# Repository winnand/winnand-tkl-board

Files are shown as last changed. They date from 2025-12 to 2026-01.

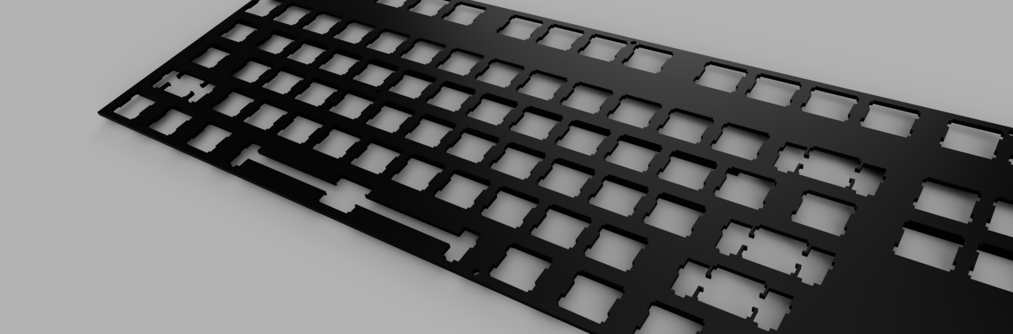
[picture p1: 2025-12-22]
Images/KB Plate.png

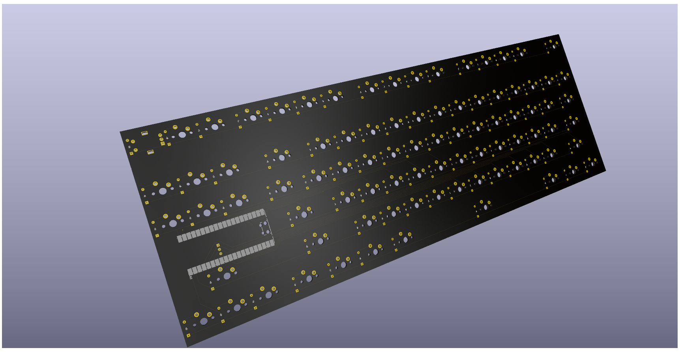
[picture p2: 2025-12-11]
Images/KeyboardPCBBackBare.png

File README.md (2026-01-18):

# The Winnand TKL Keyboard

This project is a custom keyboard based off of JoeScotto's guides from YouTube. It is a standard TKL Board which replaces the Pause key with a rotary encoder. It uses QMK with Vial support for on-the-go layout customization.

I made this project because I enjoyed the idea of having a keyboard that I made myself, with the features and rigidity of a top-of-the-line keyboard. I hoped that it would teach me more about firmware and microcontrollers for future projects, and have a good keyboard that I would be able to use for many years to come. 
Full CAD
KeyboardPCBFrontBare
Isogrid
KB Case Full
KB Case Render 1
KB Plate Underside
KB Plate
KeyboardPCBBackBare
KeyboardPCBFrontBare

# BOM

|Part # |Min. Quantity |Name on Seller Website |Description |Link |Color/Size |Quantity|Unit Price ($)|Total Price ($)|Running Total ($)|
|---|---|---|---|---|---|---|---|---|---|
|MX-keyboard switches |86 |Outemu Switch Mechanical Keyboard Switch 3Pin Clicky Linear Tactile Silent Switches RGB LED SMD Gaming Compatible With MX Switch|Keyboard Switches|https://www.aliexpress.us/item/3256802192387196.html  |Color: Dust-Proof Purple Axis Body: 90PCS |1 |$10.31 |$10.31 |$10.31 |
|Red LED |87 |100pcs 5mm LED Diode F5 Assorted Kit White Green Red Blue Yellow Orange Pink Purple Warm White DIY Light Emitting Diode |Diodes |https://www.aliexpress.us/item/3256806276743323.html  |Color: Red-Red |1 |$2.19 |$2.19 |$12.50 |
|EC11 Rotary Encoder |1 |5PCS/LOT 20 Position 360 Degree Rotary Encoder EC11 w Push Button 5Pin Handle Long 15/20MM With A Built In Push Button Switch |Rotary Encoder |https://www.aliexpress.us/item/3256805796819763.html? |15MM Half handle |1 |$3.30 |$3.30 |$15.80 |
|Raspberry Pi Pico |1 |Raspberry Pi Pico |Microcontroller  |https://www.sparkfun.com/raspberry-pi-pico.html | |0 |$4.60 |$0.00 |$15.80 |
|Micro USB male to panel mount USB C female|1 |USB 3.1 Type C Micro Usb2.0 With Panel Mount Screw Extension Cable Cord USB C Male To Female Extending Wire Extender Data Cord  |Adapter Cable |https://www.aliexpress.us/item/3256806244885684.html  |A3 |1 |$2.69 |$2.69 |$18.49 |
|M2 x 6mm Button Head screw |11 |10/50pcs M1.6 M2 M2.5 M3 M4 M5 M6 M8 Black Grade 10.9 Steel ISO7380 Hexagon Hex Socket Head Button Mushroom Allen Bolt Screw |Mounting Screws  |https://www.aliexpress.us/item/2251832782727837.html  |Size: M2 (50pcs) Length: 6mm |1 |$1.07 |$1.07 |$19.56 |
|MX Keycaps |TKL Layout |104pcs ABS Universal Mechanical Keyboard Keycaps Ergonomic Blank Keycaps For Cherry MX Keyboard Replacement OEM Backlit Key Cap |Keycaps |https://www.aliexpress.us/item/3256808802544300.html  |Red black |1 |$11.48 |$11.48 |$31.04 |
|Plate Mount Stabilizers |1x 6.25U 4x 2U|KEYCOOL V3 PCB Plate Mounted Stabilizer for Gaming Mechanical Keyboard Lubrication Satellite Switches for 1.2mm 1.6mm PCB 6.25U |Stabilizers |https://www.aliexpress.us/item/3256808467378574.html  |Black 4 in 1 |1 |$3.01 |$3.01 |$34.05 |
|M2, OD4mm Heatset Inserts |11 |M2 M2.5 M3 M4 M5 M6 Brass Hot Melt Insert Knurled Nut Thread Heat Molding Double Twill Injection Embedment Nut For 3D Printer |Heatset Inserts  |https://www.aliexpress.us/item/3256803396040989.html  |Size: M2(OD4mm)  Color: Length 5mm 50pcs |1 |$2.27 |$2.27 |$36.32 |
|Winnand-TKL PCB |1 |JLCPCB |PCB |https://cart.jlcpcb.com/quote?spm=Jlcpcb.Homepage.1006|Defaults except: PCB Color: Black Via Covering: Untented |5 |$4.16 |$20.80 |$57.12 |
|ARGB lights |1 |Addressable ARGB 5V LED Strip 3Pin Computer PC Case Tape Light WS2812B SMD 5050 Flexible Changeable Color Gamer Desktop Lamp |Lights |https://www.aliexpress.us/item/3256802938234249.html? |Emitting Color: 1 x 0.5m 30leds  Color: IP30 Non waterproof|1 |$4.00 |$4.00 |$61.12 |

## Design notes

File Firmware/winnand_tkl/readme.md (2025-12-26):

# winnand_tkl

winnand_tkl

*A short description of the keyboard/project*

* Keyboard Maintainer: [Aditya Itnal](https://github.com/winnand)
* Hardware Supported: *The PCBs, controllers supported*
* Hardware Availability: *Links to where you can find this hardware*

Make example for this keyboard (after setting up your build environment):

    make winnand_tkl:default

Flashing example for this keyboard:

    make winnand_tkl:default:flash

See the [build environment setup](https://docs.qmk.fm/#/getting_started_build_tools) and the [make instructions](https://docs.qmk.fm/#/getting_started_make_guide) for more information. Brand new to QMK? Start with our [Complete Newbs Guide](https://docs.qmk.fm/#/newbs).

## Bootloader

Enter the bootloader in 3 ways:

* **Bootmagic reset**: Hold down the key at (0,0) in the matrix (usually the top left key or Escape) and plug in the keyboard
* **Physical reset button**: Briefly press the button on the back of the PCB - some may have pads you must short instead
* **Keycode in layout**: Press the key mapped to `QK_BOOT` if it is available

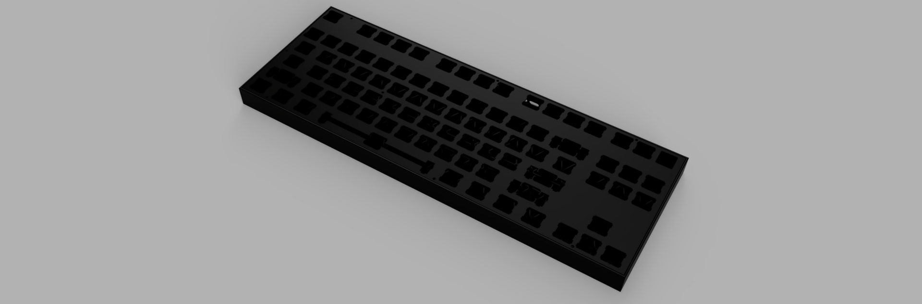
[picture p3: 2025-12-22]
Images/KB Case Full.png

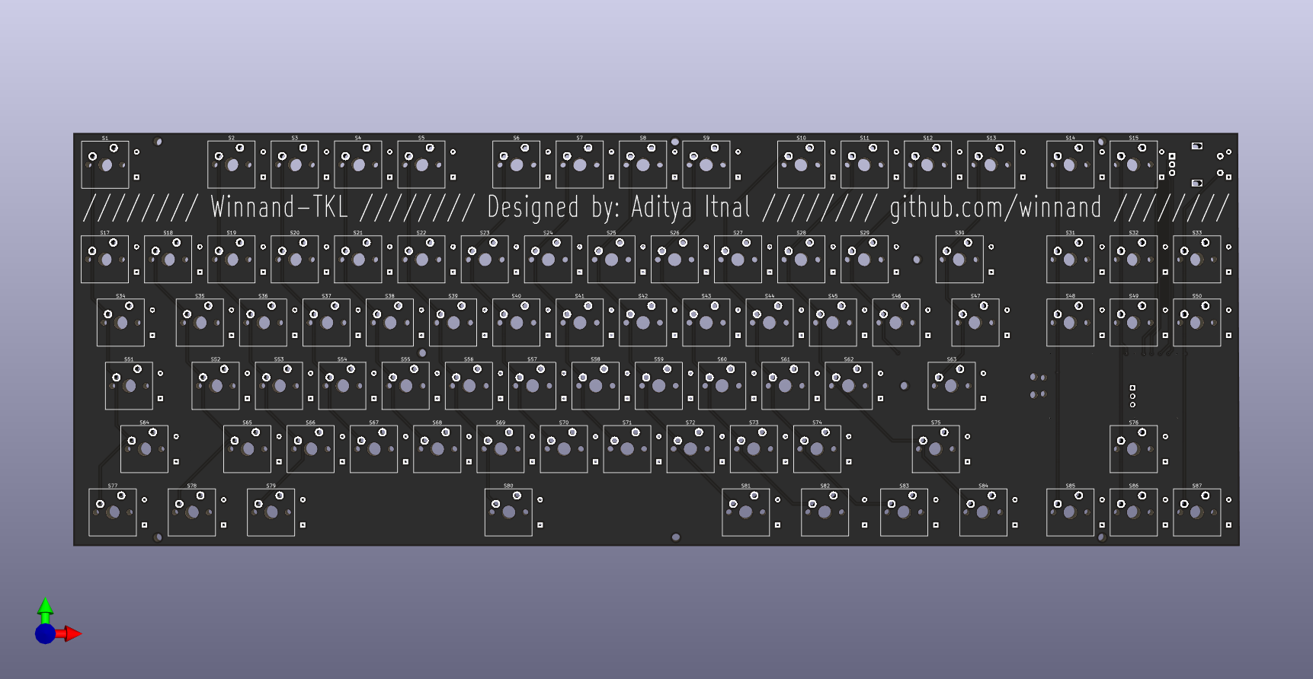
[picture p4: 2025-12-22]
Images/KeyboardPCBFrontBare.png

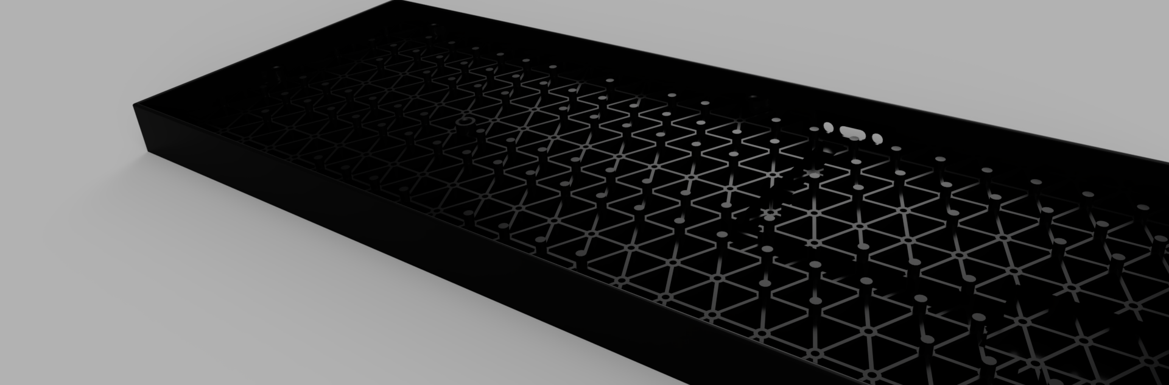
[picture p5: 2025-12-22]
Images/KB Case Render 1.PNG

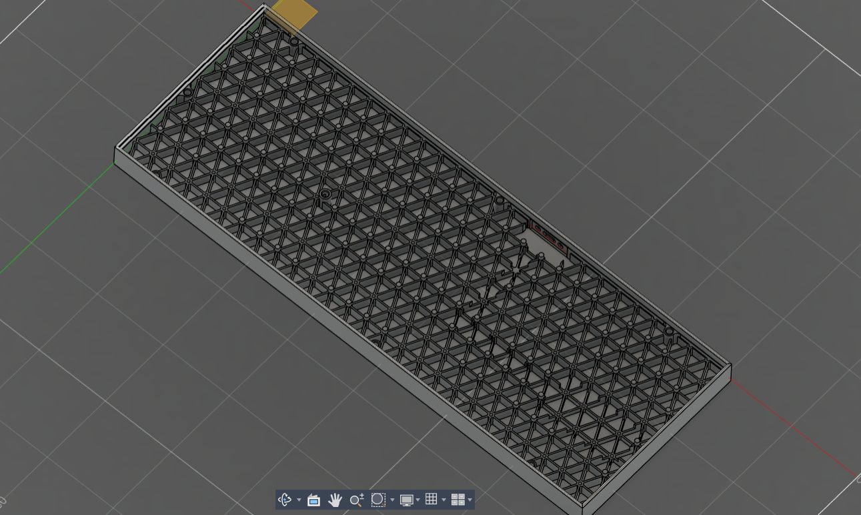
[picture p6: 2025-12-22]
Images/Isogrid.png

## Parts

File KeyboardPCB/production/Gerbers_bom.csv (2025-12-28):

Designator | Footprint | Quantity | Value | LCSC Part #
A0 | RaspberryPi_Pico_W_SMD_HandSolder | 1 | RaspberryPi_Pico_W
D1, D10, D11, D12, D13, D14, D15, D16, D17, D18, D19, D2, D20, D21, D22, D23, D24, D25, D26, D27, D28, D29, D3, D30, D31, D32, D33, D34, D35, D36, D37, D38, D39, D4, D40, D41, D42, D43, D44, D45, D46, D47, D48, D49, D5, D50, D51, D52, D53, D54, D55, D56, D57, D58, D59, D6, D60, D61, D62, D63, D64, D65, D66, D67, D68, D69, D7, D70, D71, D72, D73, D74, D75, D76, D77, D78, D79, D8, D80, D81, D82, D83, D84, D85, D86, D87, D9 | Diode_DO-35 | 87 | ~
J1 | PinHeader_1x04_P2.54mm_Vertical | 1 | Conn_01x04_Pin
S1, S10, S11, S12, S13, S14, S15, S17, S18, S19, S2, S20, S21, S22, S23, S24, S25, S26, S27, S28, S29, S3, S31, S32, S33, S35, S36, S37, S38, S39, S4, S40, S41, S42, S43, S44, S45, S46, S48, S49, S5, S50, S52, S53, S54, S55, S56, S57, S58, S59, S6, S60, S61, S62, S65, S66, S67, S68, S69, S7, S70, S71, S72, S73, S74, S76, S8, S85, S86, S87, S9 | MX_PCB_1.00u | 71 | ~
S30 | MX_PCB_2.00u | 1 | ~
S34, S47 | MX_PCB_1.50u | 2 | ~
S51 | MX_PCB_1.75u | 1 | ~
S63, S64 | MX_PCB_2.25u | 2 | ~
S75 | MX_PCB_2.75u | 1 | ~
S77, S78, S79, S81, S82, S83, S84 | MX_PCB_1.25u | 7 | ~
S80 | MX_PCB_6.25u | 1 | ~
SW0 | Encoder_EC11_MX | 1 | RotaryEncoder_Switch

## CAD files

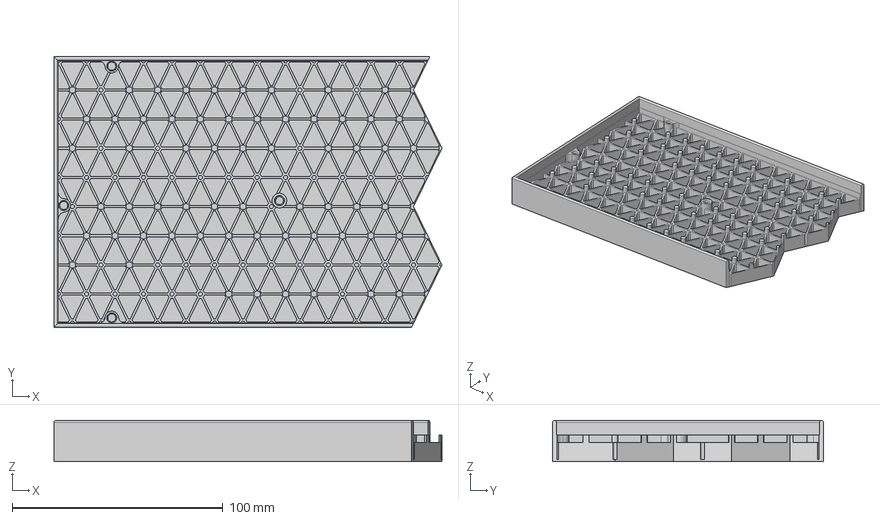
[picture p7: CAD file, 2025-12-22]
CAD/STEP Files for 3D Printing/Left Side.step
184.0 x 128.5 x 19.5 mm

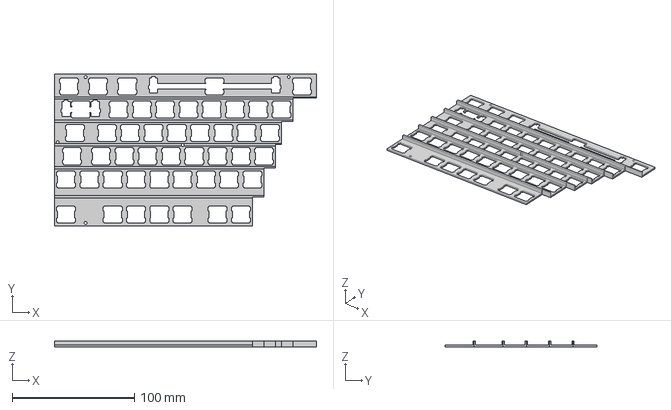
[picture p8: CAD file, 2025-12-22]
CAD/STEP Files for 3D Printing/Left Top plate.step
214.3 x 124.5 x 5.10 mm

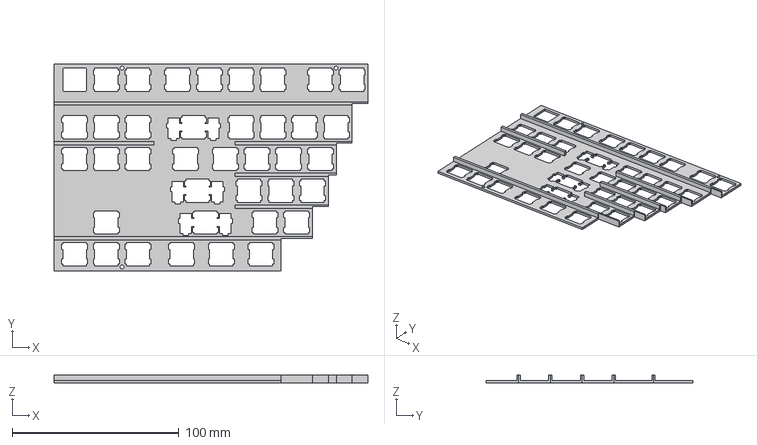
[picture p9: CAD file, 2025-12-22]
CAD/STEP Files for 3D Printing/Right Top Plate.step
188.6 x 124.5 x 5.10 mm

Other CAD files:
CAD/STEP Files for 3D Printing/Right Side.step

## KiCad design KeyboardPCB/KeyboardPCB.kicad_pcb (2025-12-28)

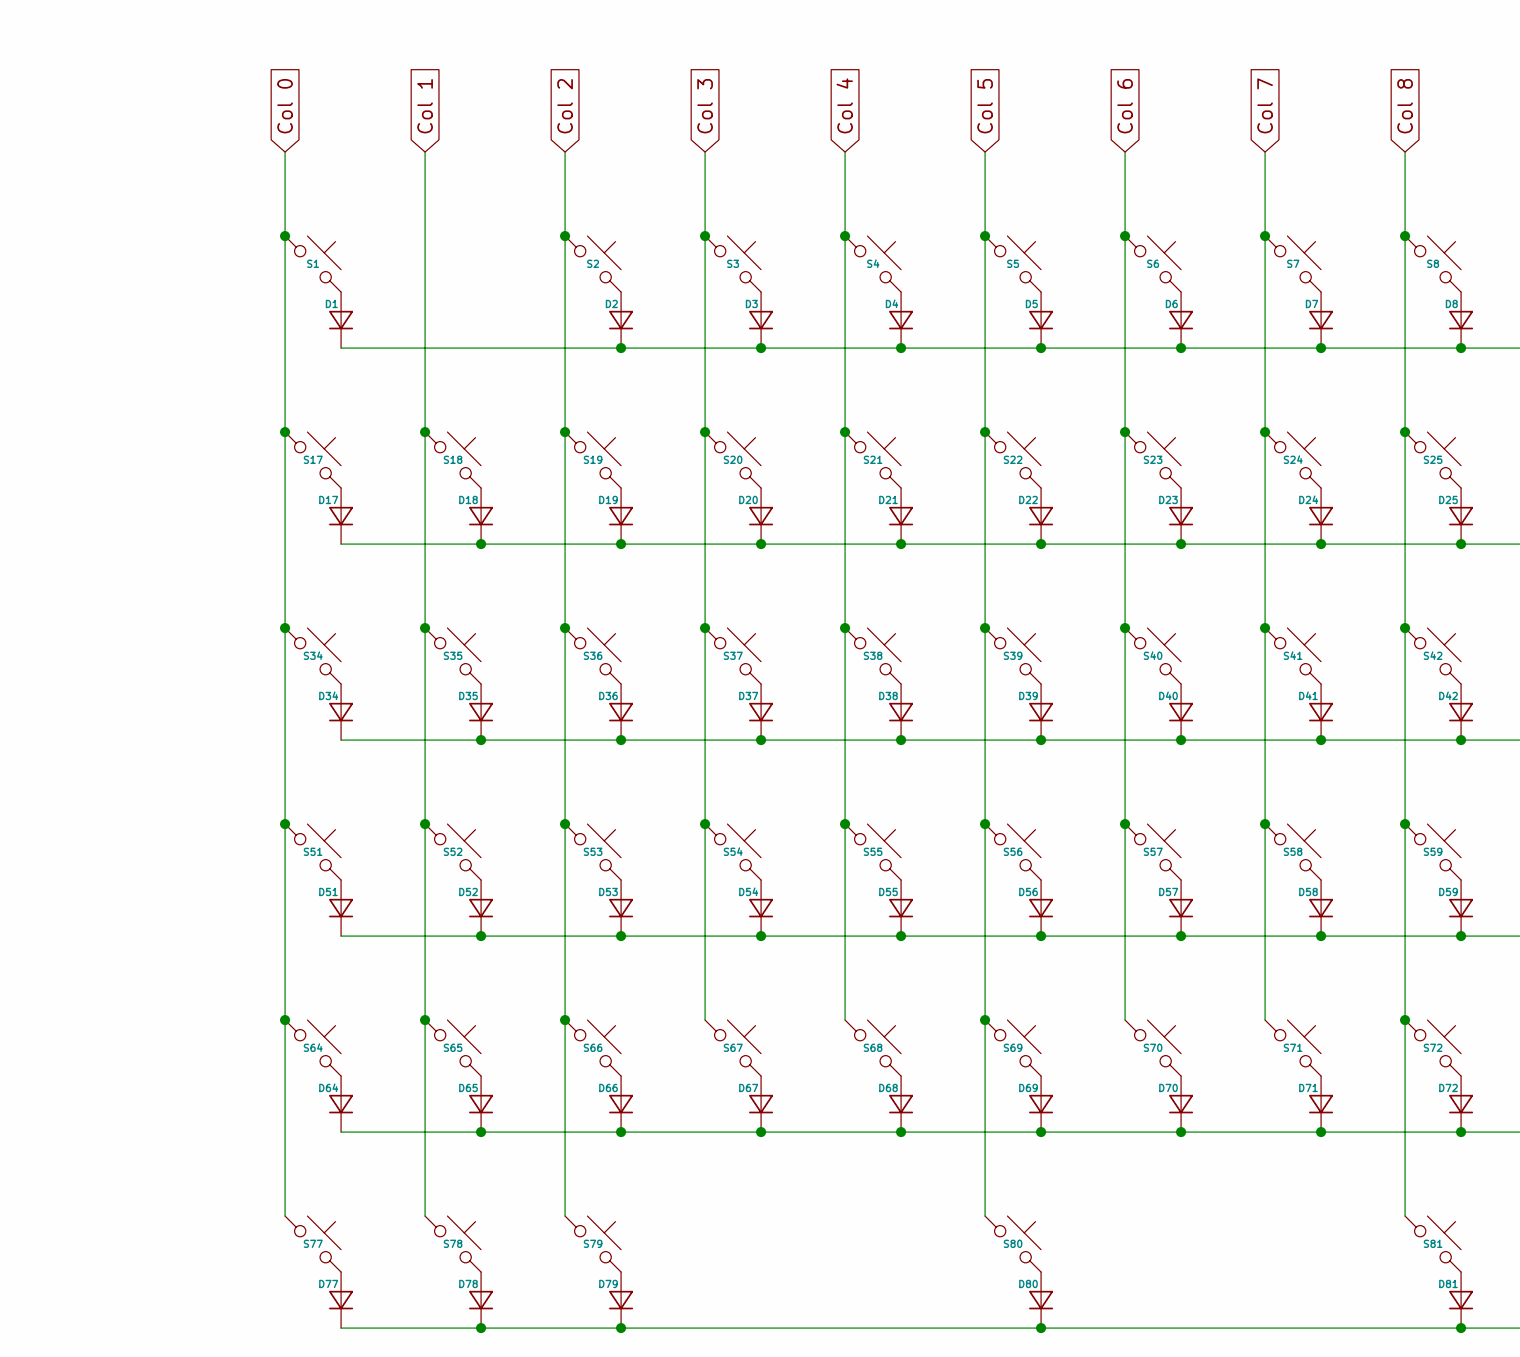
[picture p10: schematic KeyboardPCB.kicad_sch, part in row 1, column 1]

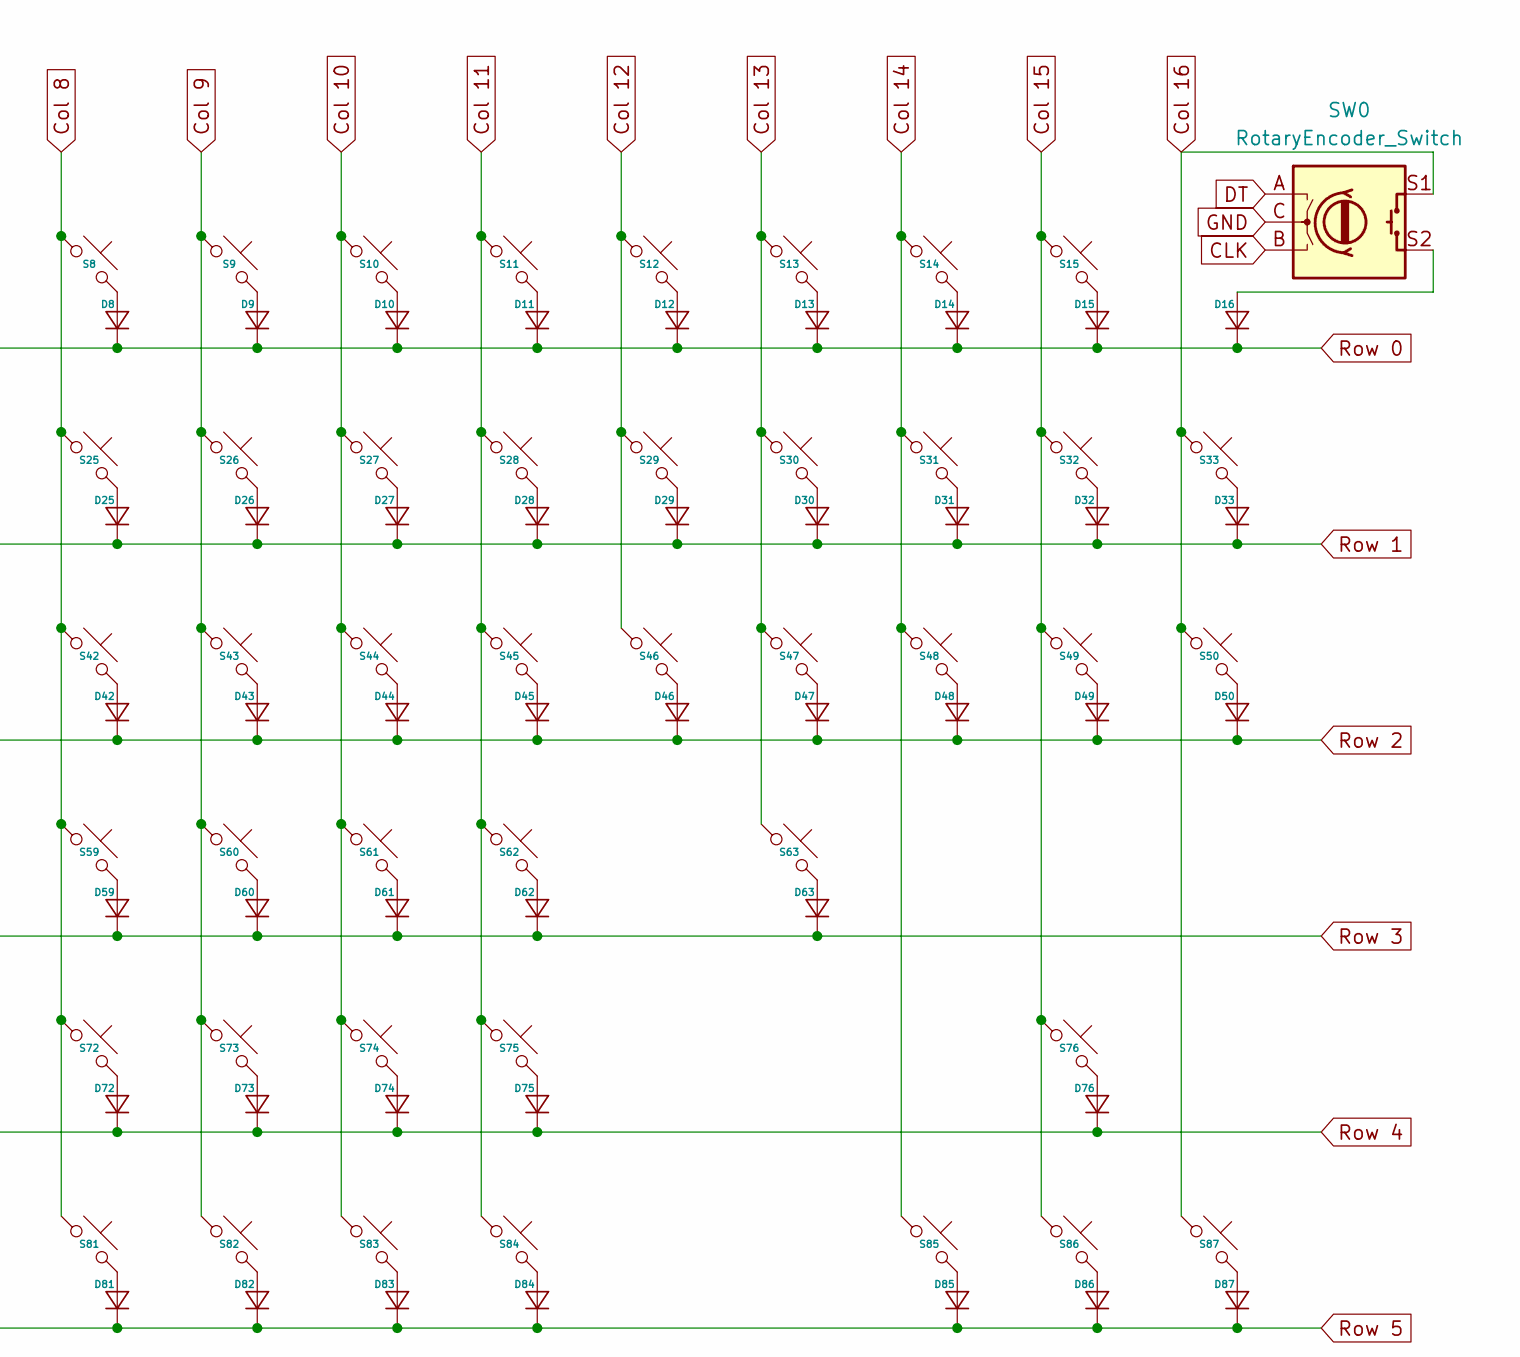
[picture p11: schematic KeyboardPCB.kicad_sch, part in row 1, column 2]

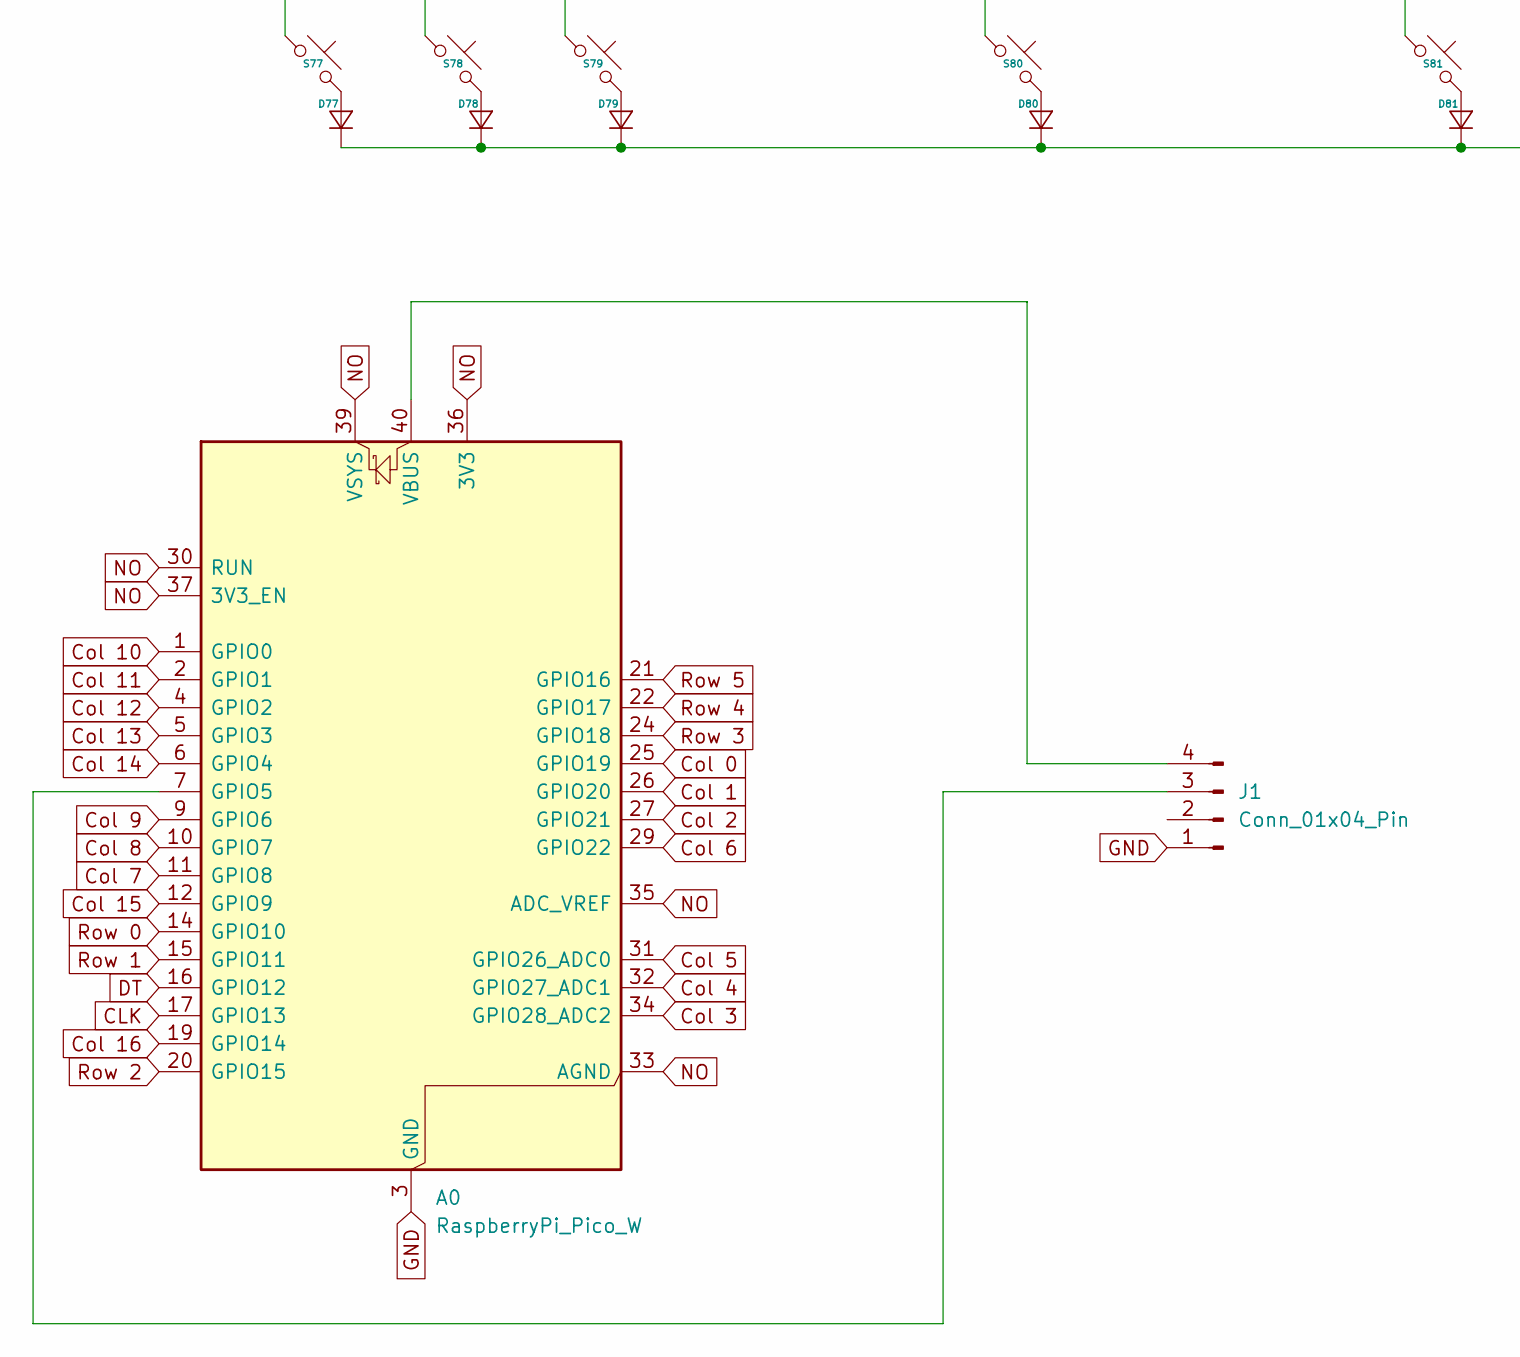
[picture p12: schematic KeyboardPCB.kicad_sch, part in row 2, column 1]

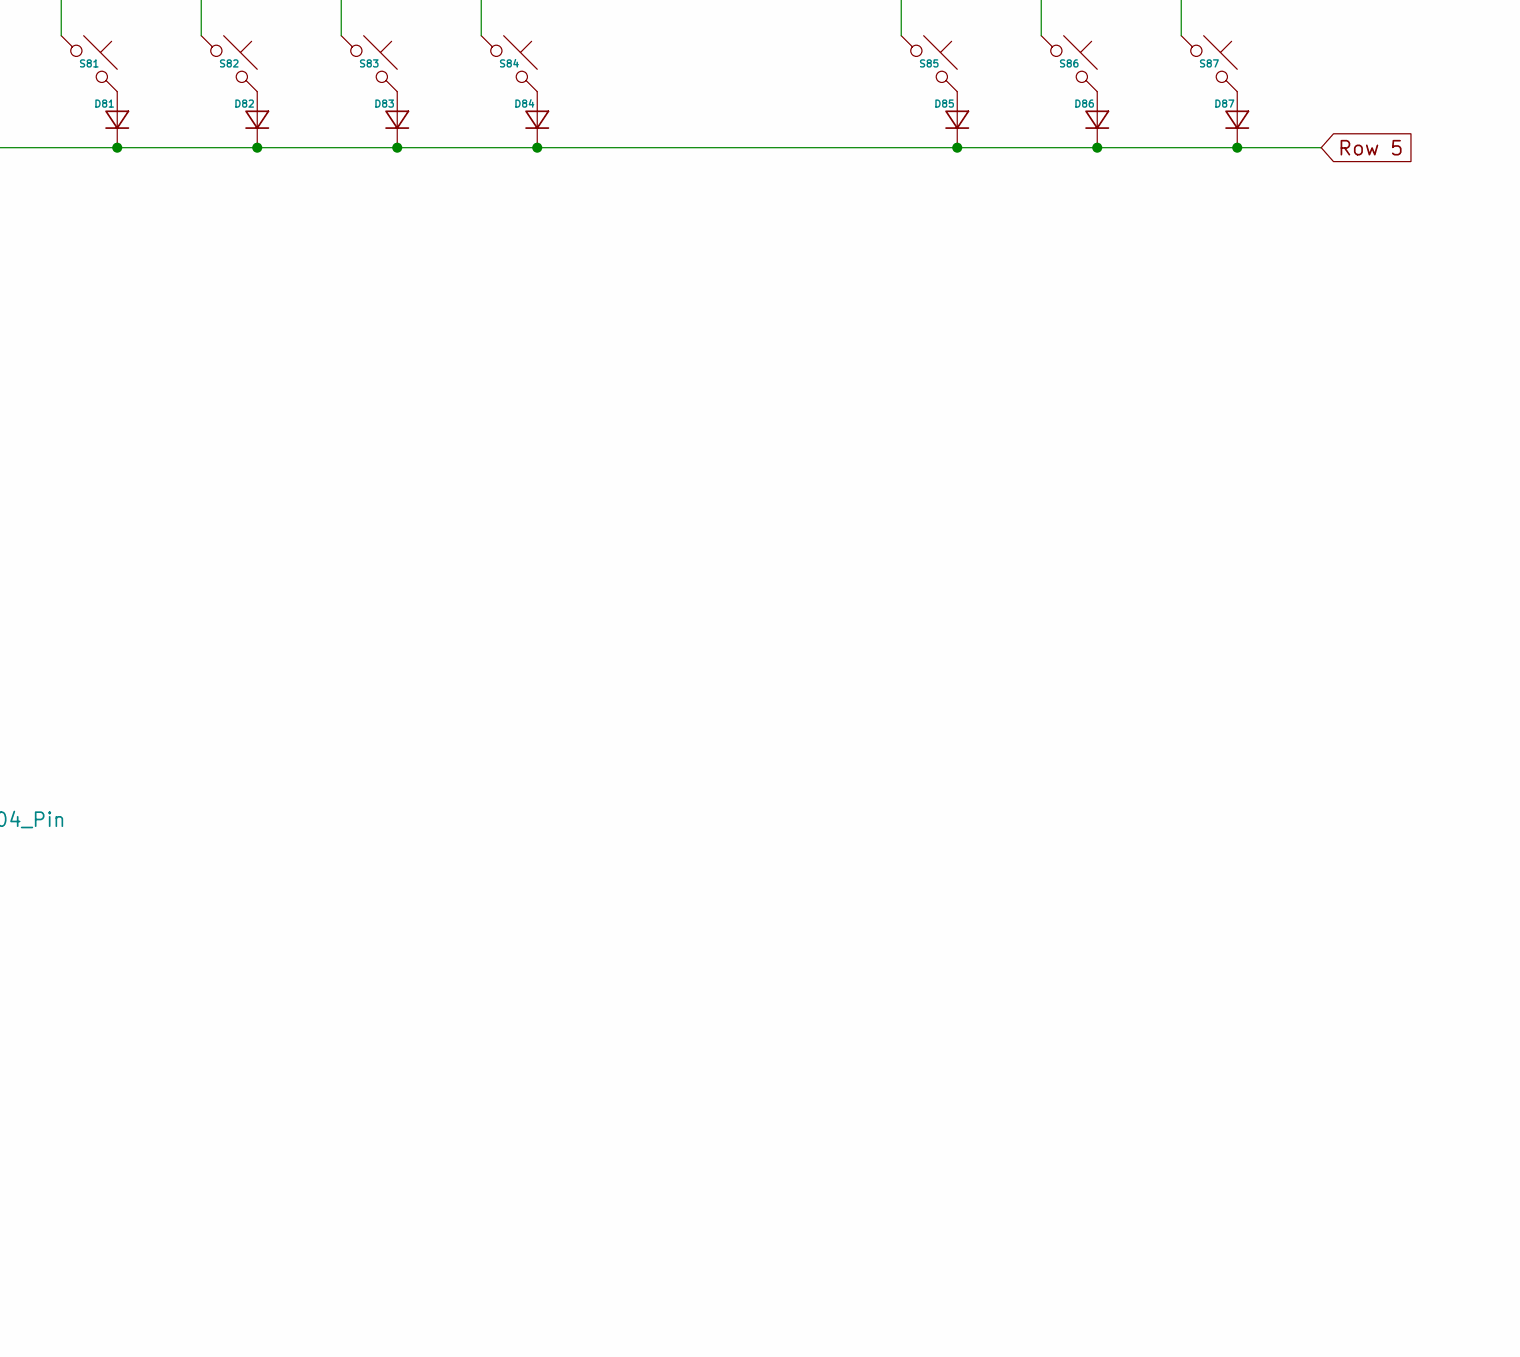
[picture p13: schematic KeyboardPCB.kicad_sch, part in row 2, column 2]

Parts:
A0: RaspberryPi_Pico_W; RaspberryPi_Pico_W_SMD_HandSolder
D1, D2, D3, D4, D5, D6, D7, D8, D9, D10, D11, D12, D13, D14, D15, D16, D17, D18, D19, D20, D21, D22, D23, D24, D25, D26, D27, D28, D29, D30, D31, D32, D33, D34, D35, D36, D37, D38, D39, D40, D41, D42, D43, D44, D45, D46, D47, D48, D49, D50, D51, D52, D53, D54, D55, D56, D57, D58, D59, D60, D61, D62, D63, D64, D65, D66, D67, D68, D69, D70, D71, D72, D73, D74, D75, D76, D77, D78, D79, D80, D81, D82, D83, D84, D85, D86, D87: Diode_DO-35
J1: Conn_01x04_Pin; PinHeader_1x04_P2.54mm_Vertical
S1, S2, S3, S4, S5, S6, S7, S8, S9, S10, S11, S12, S13, S14, S15, S17, S18, S19, S20, S21, S22, S23, S24, S25, S26, S27, S28, S29, S31, S32, S33, S35, S36, S37, S38, S39, S40, S41, S42, S43, S44, S45, S46, S48, S49, S50, S52, S53, S54, S55, S56, S57, S58, S59, S60, S61, S62, S65, S66, S67, S68, S69, S70, S71, S72, S73, S74, S76, S85, S86, S87: MX_PCB_1.00u
S30: MX_PCB_2.00u
S34, S47: MX_PCB_1.50u
S51: MX_PCB_1.75u
S63, S64: MX_PCB_2.25u
S75: MX_PCB_2.75u
S77, S78, S79, S81, S82, S83, S84: MX_PCB_1.25u
S80: MX_PCB_6.25u
SW0: RotaryEncoder_Switch; Encoder_EC11_MX

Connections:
CLK: A0.17 (GPIO13), SW0.B
Col 0: A0.25 (GPIO19), S1.1, S17.1, S34.1, S51.1, S64.1, S77.1
Col 1: A0.26 (GPIO20), S18.1, S35.1, S52.1, S65.1, S78.1
Col 2: A0.27 (GPIO21), S2.1, S19.1, S36.1, S53.1, S66.1, S79.1
Col 3: A0.34 (GPIO28_ADC2), S3.1, S20.1, S37.1, S54.1, S67.1
Col 4: A0.32 (GPIO27_ADC1), S4.1, S21.1, S38.1, S55.1, S68.1
Col 5: A0.31 (GPIO26_ADC0), S5.1, S22.1, S39.1, S56.1, S69.1, S80.1
Col 6: A0.29 (GPIO22), S6.1, S23.1, S40.1, S57.1, S70.1
Col 7: A0.11 (GPIO8), S7.1, S24.1, S41.1, S58.1, S71.1
Col 8: A0.10 (GPIO7), S8.1, S25.1, S42.1, S59.1, S72.1, S81.1
Col 9: A0.9 (GPIO6), S9.1, S26.1, S43.1, S60.1, S73.1, S82.1
Col 10: A0.1 (GPIO0), S10.1, S27.1, S44.1, S61.1, S74.1, S83.1
Col 11: A0.2 (GPIO1), S11.1, S28.1, S45.1, S62.1, S75.1, S84.1
Col 12: A0.4 (GPIO2), S12.1, S29.1, S46.1
Col 13: A0.5 (GPIO3), S13.1, S30.1, S47.1, S63.1
Col 14: A0.6 (GPIO4), S14.1, S31.1, S48.1, S85.1
Col 15: A0.12 (GPIO9), S15.1, S32.1, S49.1, S76.1, S86.1
Col 16: A0.19 (GPIO14), S33.1, S50.1, S87.1, SW0.S1
DT: A0.16 (GPIO12), SW0.A
GND: A0.3 (GND), A0.8 (GND), A0.13 (GND), A0.18 (GND), A0.23 (GND), A0.28 (GND), A0.38 (GND), J1.1, SW0.C
NO: A0.30 (RUN), A0.33 (AGND), A0.35 (ADC_VREF), A0.36 (3V3), A0.37 (3V3_EN), A0.39 (VSYS)
unnamed: A0.7 (GPIO5), J1.3
unnamed: A0.40 (VBUS), J1.4
unnamed: D1.2 (A), S1.2
unnamed: D2.2 (A), S2.2
unnamed: D3.2 (A), S3.2
unnamed: D4.2 (A), S4.2
unnamed: D5.2 (A), S5.2
unnamed: D6.2 (A), S6.2
unnamed: D7.2 (A), S7.2
unnamed: D8.2 (A), S8.2
unnamed: D9.2 (A), S9.2
unnamed: D10.2 (A), S10.2
unnamed: D11.2 (A), S11.2
unnamed: D12.2 (A), S12.2
unnamed: D13.2 (A), S13.2
unnamed: D14.2 (A), S14.2
unnamed: D15.2 (A), S15.2
unnamed: D16.2 (A), SW0.S2
unnamed: D17.2 (A), S17.2
unnamed: D18.2 (A), S18.2
unnamed: D19.2 (A), S19.2
unnamed: D20.2 (A), S20.2
unnamed: D21.2 (A), S21.2
unnamed: D22.2 (A), S22.2
unnamed: D23.2 (A), S23.2
unnamed: D24.2 (A), S24.2
unnamed: D25.2 (A), S25.2
unnamed: D26.2 (A), S26.2
unnamed: D27.2 (A), S27.2
unnamed: D28.2 (A), S28.2
unnamed: D29.2 (A), S29.2
unnamed: D30.2 (A), S30.2
unnamed: D31.2 (A), S31.2
unnamed: D32.2 (A), S32.2
unnamed: D33.2 (A), S33.2
unnamed: D34.2 (A), S34.2
unnamed: D35.2 (A), S35.2
unnamed: D36.2 (A), S36.2
unnamed: D37.2 (A), S37.2
unnamed: D38.2 (A), S38.2
unnamed: D39.2 (A), S39.2
unnamed: D40.2 (A), S40.2
unnamed: D41.2 (A), S41.2
unnamed: D42.2 (A), S42.2
unnamed: D43.2 (A), S43.2
unnamed: D44.2 (A), S44.2
unnamed: D45.2 (A), S45.2
unnamed: D46.2 (A), S46.2
unnamed: D47.2 (A), S47.2
unnamed: D48.2 (A), S48.2
unnamed: D49.2 (A), S49.2
unnamed: D50.2 (A), S50.2
unnamed: D51.2 (A), S51.2
unnamed: D52.2 (A), S52.2
unnamed: D53.2 (A), S53.2
unnamed: D54.2 (A), S54.2
unnamed: D55.2 (A), S55.2
unnamed: D56.2 (A), S56.2
unnamed: D57.2 (A), S57.2
unnamed: D58.2 (A), S58.2
unnamed: D59.2 (A), S59.2
unnamed: D60.2 (A), S60.2
unnamed: D61.2 (A), S61.2
unnamed: D62.2 (A), S62.2
unnamed: D63.2 (A), S63.2
unnamed: D64.2 (A), S64.2
unnamed: D65.2 (A), S65.2
unnamed: D66.2 (A), S66.2
unnamed: D67.2 (A), S67.2
unnamed: D68.2 (A), S68.2
unnamed: D69.2 (A), S69.2
unnamed: D70.2 (A), S70.2
unnamed: D71.2 (A), S71.2
unnamed: D72.2 (A), S72.2
unnamed: D73.2 (A), S73.2
unnamed: D74.2 (A), S74.2
unnamed: D75.2 (A), S75.2
unnamed: D76.2 (A), S76.2
unnamed: D77.2 (A), S77.2
unnamed: D78.2 (A), S78.2
unnamed: D79.2 (A), S79.2
unnamed: D80.2 (A), S80.2
unnamed: D81.2 (A), S81.2
unnamed: D82.2 (A), S82.2
unnamed: D83.2 (A), S83.2
unnamed: D84.2 (A), S84.2
unnamed: D85.2 (A), S85.2
unnamed: D86.2 (A), S86.2
unnamed: D87.2 (A), S87.2
Row 0: A0.14 (GPIO10), D1.1 (K), D2.1 (K), D3.1 (K), D4.1 (K), D5.1 (K), D6.1 (K), D7.1 (K), D8.1 (K), D9.1 (K), D10.1 (K), D11.1 (K), D12.1 (K), D13.1 (K), D14.1 (K), D15.1 (K), D16.1 (K)
Row 1: A0.15 (GPIO11), D17.1 (K), D18.1 (K), D19.1 (K), D20.1 (K), D21.1 (K), D22.1 (K), D23.1 (K), D24.1 (K), D25.1 (K), D26.1 (K), D27.1 (K), D28.1 (K), D29.1 (K), D30.1 (K), D31.1 (K), D32.1 (K), D33.1 (K)
Row 2: A0.20 (GPIO15), D34.1 (K), D35.1 (K), D36.1 (K), D37.1 (K), D38.1 (K), D39.1 (K), D40.1 (K), D41.1 (K), D42.1 (K), D43.1 (K), D44.1 (K), D45.1 (K), D46.1 (K), D47.1 (K), D48.1 (K), D49.1 (K), D50.1 (K)
Row 3: A0.24 (GPIO18), D51.1 (K), D52.1 (K), D53.1 (K), D54.1 (K), D55.1 (K), D56.1 (K), D57.1 (K), D58.1 (K), D59.1 (K), D60.1 (K), D61.1 (K), D62.1 (K), D63.1 (K)
Row 4: A0.22 (GPIO17), D64.1 (K), D65.1 (K), D66.1 (K), D67.1 (K), D68.1 (K), D69.1 (K), D70.1 (K), D71.1 (K), D72.1 (K), D73.1 (K), D74.1 (K), D75.1 (K), D76.1 (K)
Row 5: A0.21 (GPIO16), D77.1 (K), D78.1 (K), D79.1 (K), D80.1 (K), D81.1 (K), D82.1 (K), D83.1 (K), D84.1 (K), D85.1 (K), D86.1 (K), D87.1 (K)

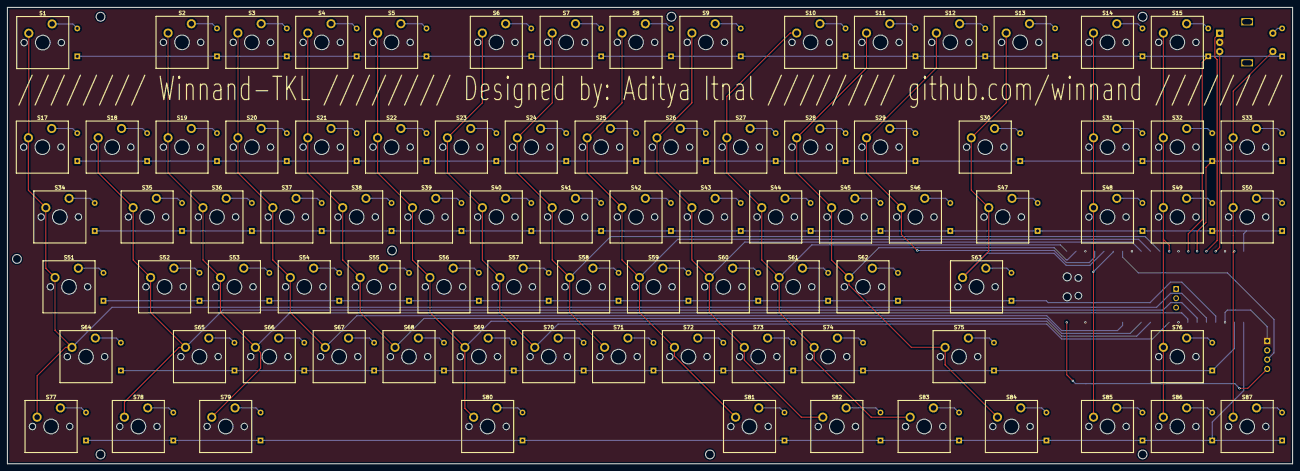
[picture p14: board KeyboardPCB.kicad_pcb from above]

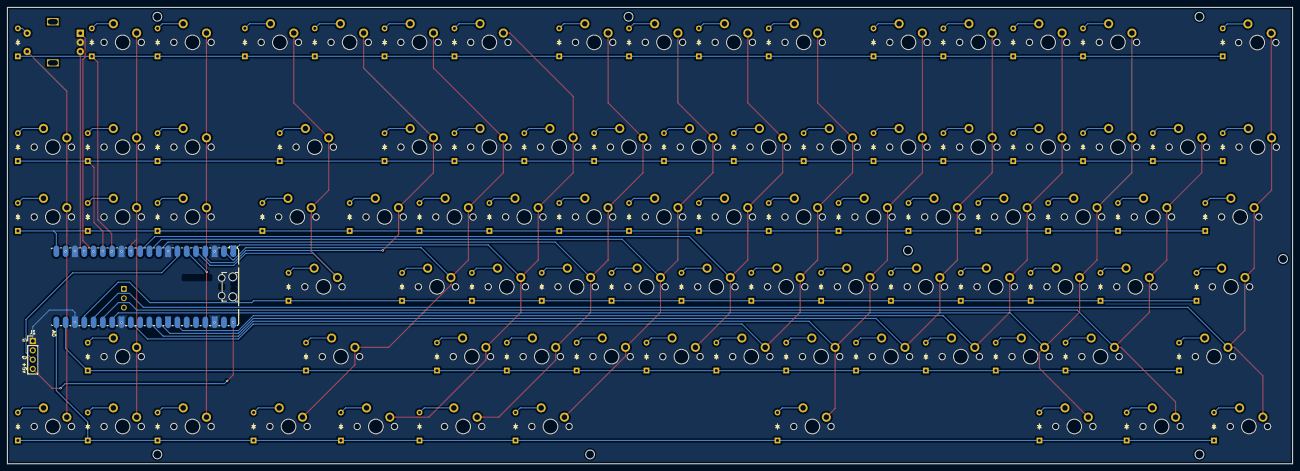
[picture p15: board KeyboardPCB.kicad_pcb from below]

Board: 2 copper layers, 350.5 x 124.5 mm, 176 parts (89 on the bottom side), 116 nets.

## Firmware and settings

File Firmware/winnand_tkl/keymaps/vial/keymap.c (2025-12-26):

// Copyright 2023 QMK
// SPDX-License-Identifier: GPL-2.0-or-later

#include QMK_KEYBOARD_H


const uint16_t PROGMEM keymaps[][MATRIX_ROWS][MATRIX_COLS] = {
    /*
     * ┌───┐   ┌───┬───┬───┬───┐ ┌───┬───┬───┬───┐ ┌───┬───┬───┬───┐ ┌───┬───┬───┐
     * │Esc│   │F1 │F2 │F3 │F4 │ │F5 │F6 │F7 │F8 │ │F9 │F10│F11│F12│ │PSc│Scr│Pse│
     * └───┘   └───┴───┴───┴───┘ └───┴───┴───┴───┘ └───┴───┴───┴───┘ └───┴───┴───┘
     * ┌───┬───┬───┬───┬───┬───┬───┬───┬───┬───┬───┬───┬───┬───────┐ ┌───┬───┬───┐
     * │ ` │ 1 │ 2 │ 3 │ 4 │ 5 │ 6 │ 7 │ 8 │ 9 │ 0 │ - │ = │ Backsp│ │Ins│Hom│PgU│
     * ├───┴─┬─┴─┬─┴─┬─┴─┬─┴─┬─┴─┬─┴─┬─┴─┬─┴─┬─┴─┬─┴─┬─┴─┬─┴─┬─────┤ ├───┼───┼───┤
     * │ Tab │ Q │ W │ E │ R │ T │ Y │ U │ I │ O │ P │ [ │ ] │  \  │ │Del│End│PgD│
     * ├─────┴┬──┴┬──┴┬──┴┬──┴┬──┴┬──┴┬──┴┬──┴┬──┴┬──┴┬──┴┬──┴─────┤ └───┴───┴───┘
     * │ Caps │ A │ S │ D │ F │ G │ H │ J │ K │ L │ ; │ ' │  Enter │
     * ├──────┴─┬─┴─┬─┴─┬─┴─┬─┴─┬─┴─┬─┴─┬─┴─┬─┴─┬─┴─┬─┴─┬─┴────────┤     ┌───┐
     * │ Shift  │ Z │ X │ C │ V │ B │ N │ M │ , │ . │ / │    Shift │     │ ↑ │
     * ├────┬───┴┬──┴─┬─┴───┴───┴───┴───┴───┴──┬┴───┼───┴┬────┬────┤ ┌───┼───┼───┐
     * │Ctrl│GUI │Alt │                        │ Alt│ GUI│Menu│Ctrl│ │ ← │ ↓ │ → │
     * └────┴────┴────┴────────────────────────┴────┴────┴────┴────┘ └───┴───┴───┘
     */

    

    [0] = LAYOUT_tkl_ansi(
        KC_ESC,           KC_F1,   KC_F2,   KC_F3,   KC_F4,   KC_F5,   KC_F6,   KC_F7,   KC_F8,   KC_F9,   KC_F10,  KC_F11,  KC_F12,     KC_PSCR, KC_SCRL, KC_PAUS,

        KC_GRV,  KC_1,    KC_2,    KC_3,    KC_4,    KC_5,    KC_6,    KC_7,    KC_8,    KC_9,    KC_0,    KC_MINS, KC_EQL,  KC_BSPC,    KC_INS,  KC_HOME, KC_PGUP,
        KC_TAB,  KC_Q,    KC_W,    KC_E,    KC_R,    KC_T,    KC_Y,    KC_U,    KC_I,    KC_O,    KC_P,    KC_LBRC, KC_RBRC, KC_BSLS,    KC_DEL,  KC_END,  KC_PGDN,
        KC_CAPS, KC_A,    KC_S,    KC_D,    KC_F,    KC_G,    KC_H,    KC_J,    KC_K,    KC_L,    KC_SCLN, KC_QUOT,          KC_ENT,
        KC_LSFT,          KC_Z,    KC_X,    KC_C,    KC_V,    KC_B,    KC_N,    KC_M,    KC_COMM, KC_DOT,  KC_SLSH,          KC_RSFT,             KC_UP,
        KC_LCTL, KC_LGUI, KC_LALT,                            KC_SPC,                             KC_RALT, MO(1), KC_APP,  KC_RCTL,    KC_LEFT, KC_DOWN, KC_RGHT
    ),

    [1] = LAYOUT_tkl_ansi(
        KC_NO,            KC_NO,   KC_NO,   KC_NO,   KC_NO,   KC_NO,   KC_NO,   KC_NO,   KC_NO,   KC_NO,   KC_NO,   KC_NO,   KC_NO,      KC_NO,   KC_NO,   KC_NO,
                                                                                                                                                                         
        KC_NO,   KC_NO,   KC_NO,   KC_NO,   KC_NO,   KC_NO,   KC_NO,   KC_NO,   KC_NO,   KC_NO,   KC_NO,   KC_NO,   KC_NO,   KC_NO,      KC_NO,   KC_NO,   KC_NO,
        KC_NO,   KC_NO,   KC_NO,   KC_NO,   KC_NO,   KC_NO,   KC_NO,   KC_NO,   KC_NO,   KC_NO,   KC_NO,   KC_NO,   KC_NO,   KC_NO,      KC_NO,   KC_NO,   KC_NO,
        KC_NO,   KC_NO,   KC_NO,   KC_NO,   KC_NO,   KC_NO,   KC_NO,   KC_NO,   KC_NO,   KC_NO,   KC_NO,   KC_NO,            KC_NO,
        KC_NO,            KC_NO,   KC_NO,   KC_NO,   KC_NO,   KC_NO,   KC_NO,   KC_NO,   KC_NO,   KC_NO,   KC_NO,            KC_NO,               KC_NO,
        KC_NO,   KC_NO,   KC_NO,                            KC_NO,                                KC_NO,   KC_NO,   KC_NO,   KC_NO,      KC_NO,   KC_NO,   KC_NO
    )

};

#if defined(ENCODER_MAP_ENABLE)
	const uint16_t PROGMEM encoder_map[][NUM_ENCODERS][NUM_DIRECTIONS] = {
		[0]	= { ENCODER_CCW_CW(LCTL(KC_TAB), LCTL(LSFT(KC_TAB))) },
		[1]	= { ENCODER_CCW_CW(KC_VOLD, KC_VOLU) }
	};
#endif

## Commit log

2025-12-10 Schematic and initial PCB design
    [KeyboardPCB.kicad_pcb, KeyboardPCB.kicad_sch]
2025-12-11 Finished PCB v1
    [KeyboardPCB.kicad_pcb, KeyboardPCB.kicad_sch]
2025-12-22 CAD Files
    [KeyboardPCB-B_Cu.gbr, KeyboardPCB-B_Mask.gbr, KeyboardPCB-B_Paste.gbr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]
2025-12-22 Keyboard Case Master Fusion File
2025-12-22 updated README and BOM
    [BOM.csv, KeyboardPCB.csv]
2025-12-26 Added Firmware files
    [BOM.csv]
2025-12-28 added RGB header
    [Gerbers_bom.csv, Gerbers_designators.csv, Gerbers_positions.csv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]
2025-12-28 added rgb to the BOM
    [BOM.csv]
2026-01-18 Added per-key LED lighting
    [BOM.csv]
